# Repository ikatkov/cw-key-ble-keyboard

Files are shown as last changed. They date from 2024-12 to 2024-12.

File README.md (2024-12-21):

# Morse Code Keyer BLE

## Overview
This project is a Bluetooth keyboard for a Morse Code keyer. 

Main purpose is to practice morse code in the Morse Mania iOS app with a real morse code key.

Data flow looks like this

a CW Keyer -over audio-wire-> this BT Keyboard box --over BT-> iPhone

The Morse Mania app expect "[" and "]" buttons, so this Bluetooth keyboard sends key_down and key_up events.

### Battery level
On iOS battery level is visible in Battery widget - Swipe right on the Home Screen to access the Today View.
### Multiple languages
If you have more than one language installed, you must switch to "English" before this BT keyboard connects. If you don't the Morse Mania app would be gettting whatever your national symbols are mapped to the "[" and "]" buttons on the standard keyboard and the app would looks broken.

### Key repeat
You might want to disable auto-key repeat in iOS Settings > Accessibility > Keyboards

## Features
- BLE keyboard functionality
- Tone generation for startup and shutdown
- Voltage detection to monitor battery status, audio bips when voltage is below ~2.9V
- Inactivity 5min auto turn-off

## Usage
- Connect the Arduino to your computer and upload the code.
- Open a BLE-capable device and connect to the "Morse Code Keyer".
- Use the iambic CW paddles to send Morse code.

## Assembly

See schematic and PCB in the  "kicad" folder.
The firmware in the "firmware" folder.

[See interactive PCB 3d view here](https://3dviewer.net/#model=https://github.com/ikatkov/cw-key-ble-keyboard/main/pcb.wrl)

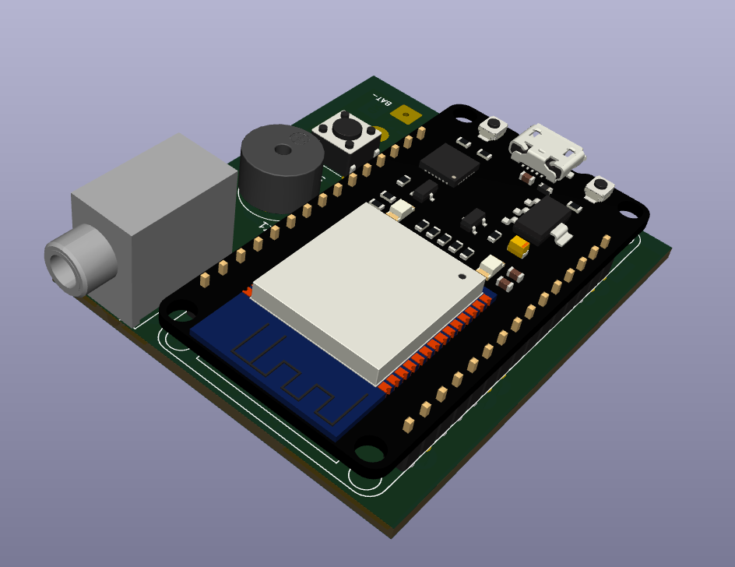
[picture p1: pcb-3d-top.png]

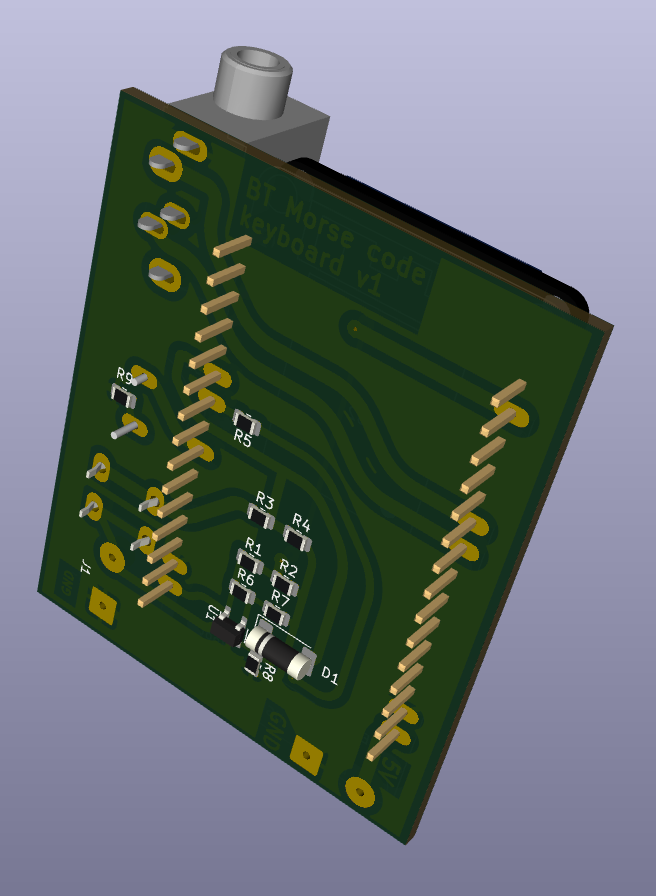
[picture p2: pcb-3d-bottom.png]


## Acknowledgments
- [Arduino](https://www.arduino.cc/)
- [BleKeyboard Library](https://github.com/Teckel12/BLEKeyboard)

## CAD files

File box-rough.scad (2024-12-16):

/* Box design originally by:
////////////////////////////////////////////////////////////////////
              -    FB Aka Heartman/Hearty 2016     -
              -   http://heartygfx.blogspot.com    -
              -       OpenScad Parametric Box      -
              -         CC BY-NC 3.0 License       -
////////////////////////////////////////////////////////////////////

Improved by jbebel:
http://github.com/jbebel/Ultimate-Box-Maker

To create a box, start by modifying the numerical parameters in the sections
below. This can be accomplished using a release of OpenSCAD newer than 2015.03.
As of the time of writing, this means that a development snapshot is required.
The Thingiverse Customizer may also potentially work, but at the time of
writing, it was inoperable.

The simplest choice is to hand-edit the .scad file. Feature toggles are
annotated with a comment. The other numerical parameters are measurements in
mm. Everything is parametrized, so if you double all the non-feature parameters
you will double the box size in every dimension. Certain parameters are derived
from other parameters. If you wish to override them, you may, but sensible
defaults have been chosen. Notably the design in this revision is particularly
PCB-centric, in that you should start with your PCB size and adjust the margins
around it to determine the box size. If you care more about the box size, you
can set the Length, Width, and Height explicitly, but read the comments around
them.

Once your box is sized appropriately, you can use the Panel modules to design
the holes and text for the front and back panels. Helper variables are provided
to assist you in positioning these holes relative to the PCB, if your holes are
for PCB-mounted components.

When you are ready to print, adjust the values in the "STL element to export"
section, and export each part one at a time.

Experimental options are provided for a screwless design, but these are
untested. In particular, the box fixation tabs may need thicknesses adjusted
in order to have the appropriate flexibility.
*/

// preview[view:north east, tilt:top diagonal]
//----------------------- Box parameters ---------------------------

/* [Box options] */
// - Wall thickness
Thick = 2;
// - Panel thickness
PanelThick = 2;
// - Font Thickness
FontThick = 0.5;
// - Filet Radius
Filet = 2;
// - 0 for beveled, 1 for rounded
Round = 1; // [0:No, 1:Yes]
// - Printer margin around interior cutouts
CutoutMargin = 0.3;
// - Margin between mating parts
PartMargin = 0.1;
// - PCB feet? (x4)
PCBFeet = 1; // [0:No, 1:Yes]
// - Decorations?
Decorations = 1; // [0:No, 1:Yes]
// - Decorations to ventilation holes
Vent = 1; // [0:No, 1:Yes]
// - Decoration-Holes width (in mm)
Vent_width = 1.5;
// - Tolerance (Panel/rails gap on one edge)
PanelThickGap = CutoutMargin + PartMargin;
PanelVerticalGap = PartMargin;
PanelHorizontalGap = CutoutMargin + PartMargin;


/* [Box Fixation Tabs] */
// - Side screw hole (or snap) diameter
ScrewHole = 2.2606;
// - Screw thread major diameter for outer shell
BoxHole = 2.8448;
// Thickness of fixation tabs
TabThick = 2;
// Back left tab
BLTab = 1; // [0:Bottom, 1:Top]
// Back right tab
BRTab = 1; // [0:Bottom, 1:Top]
// Front left tab
FLTab = 1; // [0:Bottom, 1:Top]
// Front right tab
FRTab = 1; // [0:Bottom, 1:Top]
// EXPERIMENTAL: Snap tabs
SnapTabs = 0; // [0:Screws, 1:Snaps]


/* [PCB options] */
// - PCB Length
PCBLength = 54;
// - PCB Width
PCBWidth = 68;
// - PCB Thickness
PCBThick = 1.6;
// You likely need to maintain |TabThick| margin on the left and right for tabs
// and whatnot.
// - Margin between front panel and PCB
FrontEdgeMargin = 2;
// - Margin between back panel and PCB
BackEdgeMargin = 2;
// - Margin between left wall and PCB
LeftEdgeMargin = 5;
// - Margin between right wall and PCB
RightEdgeMargin = 5;
// - Margin between top of PCB and box top.
TopMargin = 20;


/* [PCB_Feet] */
// - Foot height above box interior
FootHeight = 3;
// - Foot diameter
FootDia = 8;
// - Hole diameter, or peg for screwless design
FootHole = 0; // tap size for #4 coarse-thread
// - EXPERIMENTAL Screwless design
Screwless = 0; // [0:Screws, 1:Screwless]
FootFilet = FootHeight/4;

// Foot centers are specified as distance from PCB back-left corner.
// X is along the "length" axis, and Y is along the "width" axis.
// - Foot 1 distance from back PCB edge
Foot1X = 5;
// - Foot 1 distance from left PCB edge
Foot1Y = 5;
// - Foot 2 distance from back PCB edge
Foot2X = 5;
// - Foot 2 distance from right PCB edge
Foot2YFromEdge = 5;
Foot2Y = PCBWidth - Foot2YFromEdge;
// - Foot 3 distance from front PCB edge
Foot3XFromEdge = 5;
Foot3X = PCBLength - Foot3XFromEdge;
// - Foot 3 distance from left PCB edge
Foot3Y = 5;
// - Foot 4 distance from front PCB edge
Foot4XFromEdge = 5;
Foot4X = PCBLength - Foot4XFromEdge;
// - Foot 4 distance from right PCB edge
Foot4YFromEdge = 5;
Foot4Y = PCBWidth - Foot4YFromEdge;


/* [STL element to export] */
// - Top shell
TShell = 0; // [0:No, 1:Yes]
// - Bottom shell
BShell = 0; // [0:No, 1:Yes]
// - Front panel
FPanL = 1; // [0:No, 1:Yes]
// - Back panel
BPanL = 0; // [0:No, 1:Yes]
// - Panel holes and text
PanelFeatures = 0; // [0:No, 1:Yes]


/* [Hidden] */
// - Shell color
Couleur1 = "Orange";
// - Panel color
Couleur2 = "OrangeRed";
// - Text color
TextColor = "White";
// - making decorations thicker if it is a vent to make sure they go through
// shell
// Add a small number to Thick in case Filet is 0.
Dec_Thick = Vent ? Thick*1.001 + Filet : Thick/2;
// Separate vents with a square pillar by default.
Dec_Spacing = Thick + Vent_width;
// X offset to center of first vent
Dec_Offset = Thick*2 + PanelThick + PanelThickGap*2 + Dec_Spacing - Vent_width/2;

// Resolution based on Round parameter. Set this first number to something
// smaller to speed up processing. It should always be a multiple of 4.
Resolution = Round ? 100: 4;

/* Calculate box dimensions from PCB. If you want a more box-centric design
   where the outer diameter of the box matters more than the margins around
   the PCB you can set these manually. The PCB will still be placedaccording
   to the left and back margins, and if you want to use the screwless box
   design, you will need to set the TopMargin to
   (Height - Thick*2 - FootHeight - PCBThick)
*/
Length = PCBLength + FrontEdgeMargin + BackEdgeMargin + ((Thick + PanelThick + PanelThickGap*2)*2);
Width = PCBWidth + LeftEdgeMargin + RightEdgeMargin + Thick*2;
Height = FootHeight + PCBThick + TopMargin + Thick*2;
echo("Box: ", Length=Length, Width=Width, Height=Height);
// X position inset of mounting holes and tabs
MountInset = Thick*3 + PanelThick + PanelThickGap*2 + ScrewHole*4;

// Calculate panel dimensions from box dimensions.
PanelWidth = Width - Thick*2 - PanelHorizontalGap*2;
PanelHeight = Height - Thick*2 - PanelVerticalGap*2;


/*  Panel Manager

    Use the below 4 modules to produce holes and text on the front and back
    panels. The holes modules should contain instances of SquareHole or
    CylinderHole defined later in this file. The text modules should contain
    instances of LText or CText defined later in this file. It is
    recommended to use variables that you define for your needs to create
    the size and positions of these objects.
*/

// Calculate board-relative positions with respect to the panel, for
// convenience in placing panel elements.
TopOfBoardWRTPanel = FootHeight + PCBThick - PanelVerticalGap;
LeftEdgeOfBoardWRTFPanel = LeftEdgeMargin - PanelHorizontalGap;
LeftEdgeOfBoardWRTBPanel = RightEdgeMargin - PanelHorizontalGap;
// Visible panel edges
PanelBottomEdge = Thick - PanelVerticalGap;
PanelTopEdge = PanelHeight - Thick + PanelVerticalGap;
PanelLeftEdge = Thick - PanelHorizontalGap;
PanelRightEdge = PanelWidth - Thick + PanelHorizontalGap;


// Holes for front panel
module FPanelHoles() {
    // SquareHole(On/Off, Xpos,Ypos,Length,Width,Filet)
    SquareHole(1, 20, 20, 15, 10, 1);
    SquareHole(1, 40, 20, 15, 10, 1);
    SquareHole(1, 60, 20, 15, 10, 1);
    // CylinderHole(On/Off, Xpos, Ypos, Diameter)
    CylinderHole(1, 27, 40, 8);
    CylinderHole(1, 47, 40, 8);
    CylinderHole(1, 67, 40, 8);
    SquareHole(1, 20, 50, 80, 30, 3);
    CylinderHole(1, 93, 30, 10);
    SquareHole(1, 120, 20, 30, 60, 3);
}


// Text for front panel
module FPanelText() {
    // LText(On/Off, Xpos, Ypos, "Font", Size, "Text", "HAlign", "VAlign")
    LText(1, 20, 83, "Arial Black", 4, "Digital Screen", HAlign="left");
    LText(1, 120, 83, "Arial Black", 4, "Level", HAlign="left");
    LText(1, 20, 11, "Arial Black", 6, "  1     2      3", HAlign="left");
    // CText(On/Off, Xpos, Ypos, "Font", Size, Diameter, Arc(Deg), Starting Angle(Deg),"Text")
    CText(1, 93, 29, "Arial Black", 4, 10, 180, 0,
          ["1", "." , "3", "." , "5", "." , "7", "." , "9", "." , "11"]);
}
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

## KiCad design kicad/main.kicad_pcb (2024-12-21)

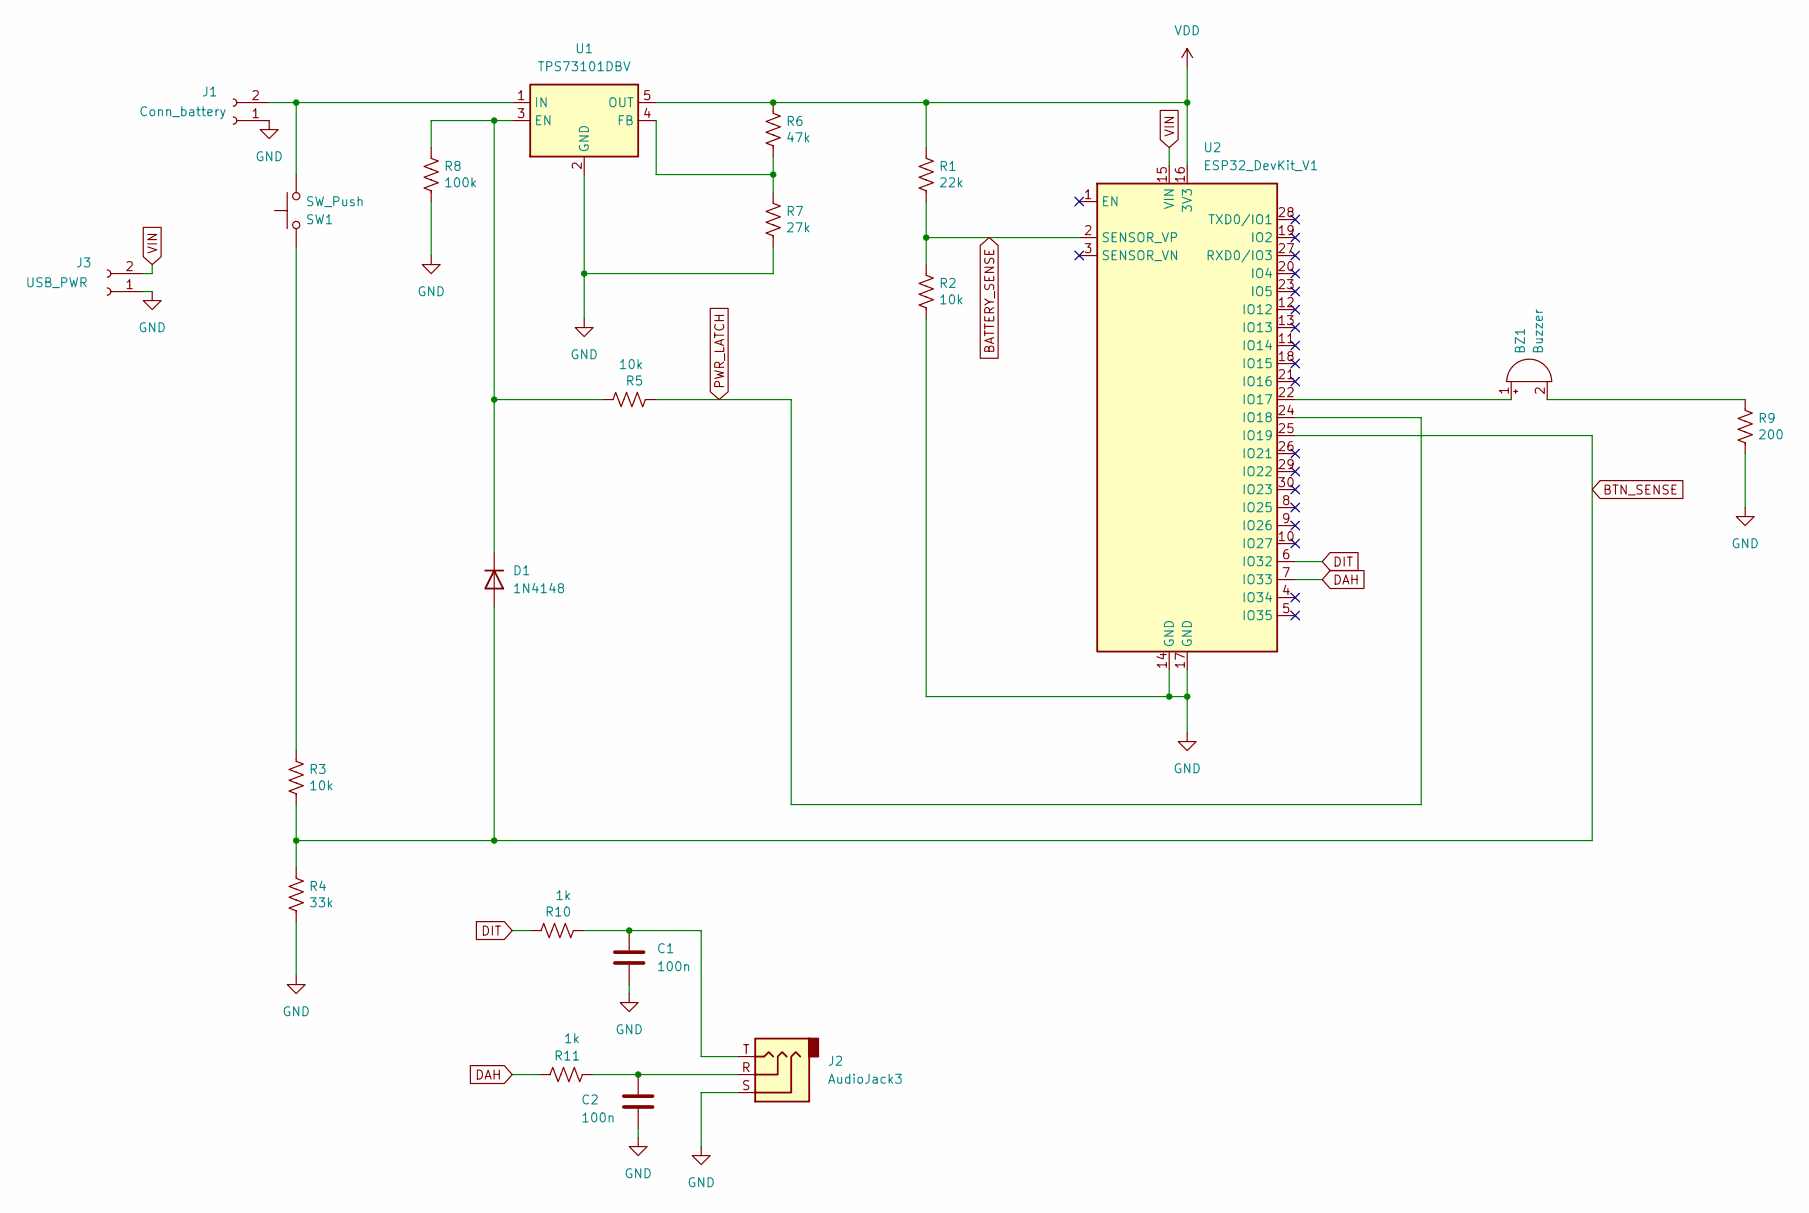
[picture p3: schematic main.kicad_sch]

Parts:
BZ1: Buzzer; Buzzer-GT-0905A
C1, C2: 100n; C_1206_3216Metric
D1: 1N4148; D_MELF
J1: Conn_battery; SolderWire-1.5sqmm_1x02_P6mm_D1.7mm_OD3mm
J2: AudioJack3; Jack_3.5mm_CUI_SJ1-3535NG_Horizontal
J3: USB_PWR; SolderWire-1.5sqmm_1x02_P6mm_D1.7mm_OD3mm
R1: 22k; R_0805_2012Metric
R2, R3, R5: 10k; R_0805_2012Metric
R4: 33k; R_0805_2012Metric
R6: 47k; R_0805_2012Metric
R7: 27k; R_0805_2012Metric
R8: 100k; R_0805_2012Metric
R9: 200; R_0805_2012Metric
R10, R11: 1k; R_0805_2012Metric
SW1: SW_Push; SW_PUSH_6mm
U1: TPS73101DBV; SOT-23-5
U2: ESP32_DevKit_V1; esp32_devkit_v1_doit

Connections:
BATTERY_SENSE: R1.2, R2.1, U2.2 (SENSOR_VP)
BTN_SENSE: D1.2 (A), R3.2, R4.1, U2.25 (IO19)
DAH: R11.1, U2.7 (IO33)
DIT: R10.1, U2.6 (IO32)
GND: C1.2, C2.2, J1.1, J2.S, J3.1, R2.2, R4.2, R7.2, R8.2, R9.2, U1.2 (GND), U2.14 (GND), U2.17 (GND)
unnamed: BZ1.1 (+), U2.22 (IO17)
unnamed: BZ1.2 (-), R9.1
unnamed: C1.1, J2.T, R10.2
unnamed: C2.1, J2.R, R11.2
unnamed: D1.1 (K), R5.1, R8.1, U1.3 (EN)
unnamed: J1.2, SW1.1, U1.1 (IN)
unnamed: R3.1, SW1.2
unnamed: R6.2, R7.1, U1.4 (FB)
PWR_LATCH: R5.2, U2.24 (IO18)
VDD: R1.1, R6.1, U1.5 (OUT), U2.16 (3V3)
VIN: J3.2, U2.15 (VIN)

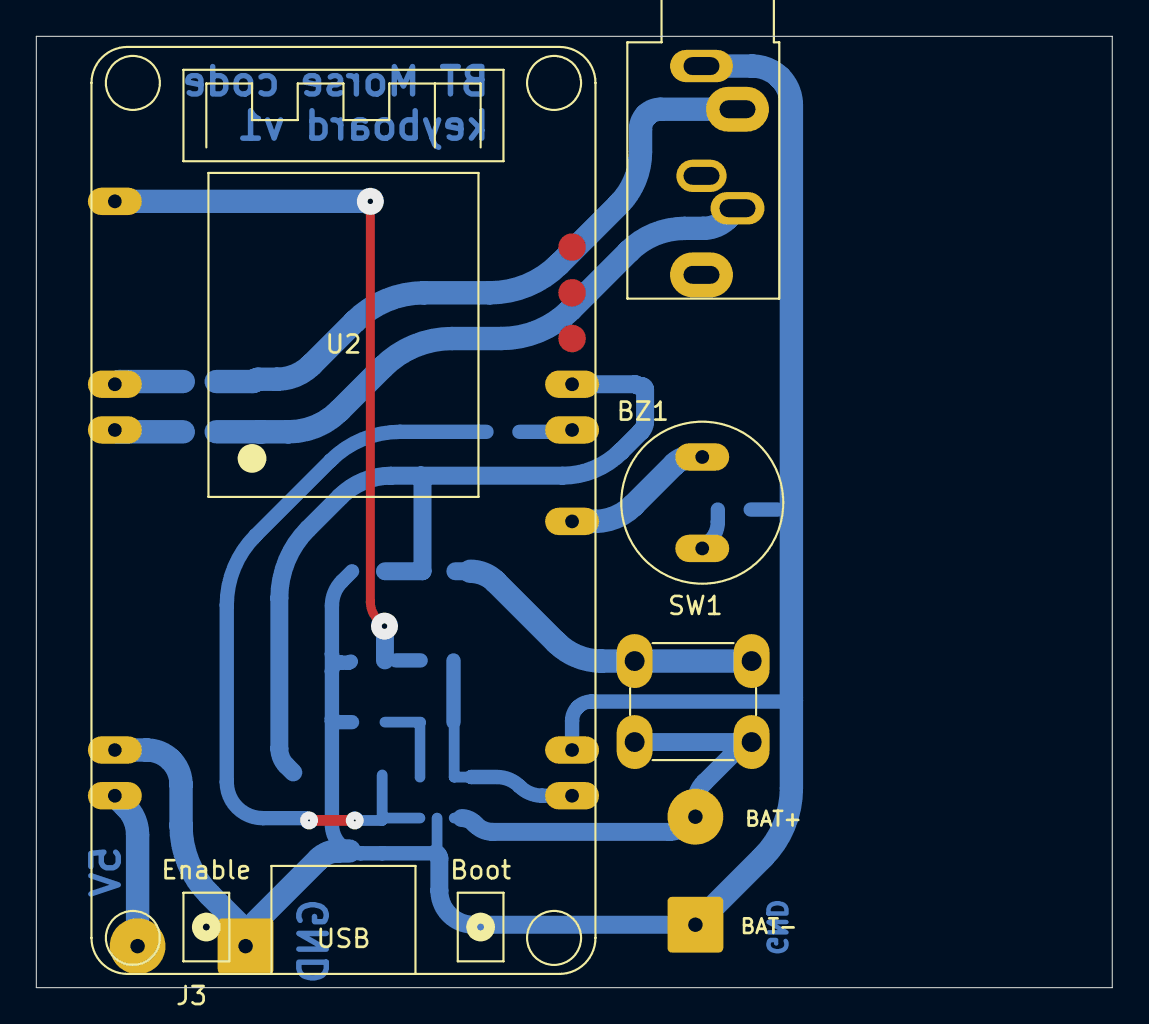
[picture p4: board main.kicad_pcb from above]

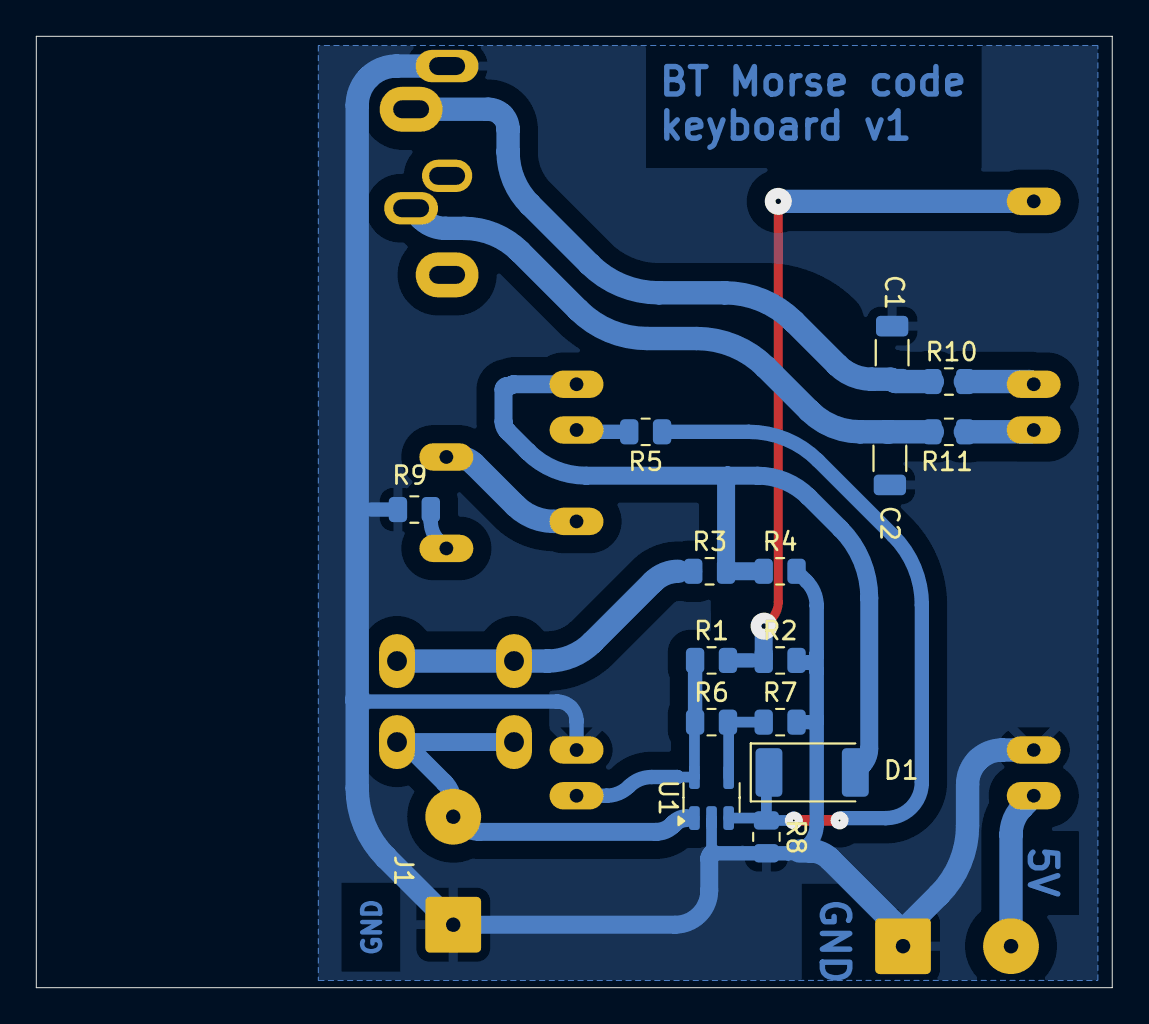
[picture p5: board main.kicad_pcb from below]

Board: 4 copper layers, 59.8 x 52.9 mm, 21 parts (16 on the bottom side), 16 nets.

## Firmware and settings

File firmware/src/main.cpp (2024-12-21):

#include <Arduino.h>
#include <BleKeyboard.h>
#include "soc/soc.h"
#include "soc/rtc_cntl_reg.h"

BleKeyboard bleKeyboard;
// #define PADDLE_DIT_PIN 4
// #define PADDLE_DAH_PIN 5
// #define POWER_LATCH_PIN 18
// #define BUTTON_SENSE_PIN 23
// #define VOLTAGE_DETECTOR_PIN 36
// #define BUZZER_PIN 22
// #define LED_PIN 19

#define PADDLE_DIT_PIN 33
#define PADDLE_DAH_PIN 32

#define VOLTAGE_DETECTOR_PIN 36
#define BUZZER_PIN 17
#define BUTTON_SENSE_PIN 19
#define POWER_LATCH_PIN 18

byte button_dit_oldSwitchState = HIGH;
byte button_dah_oldSwitchState = HIGH;
byte button_pwr_oldSwitchState = HIGH;
const unsigned long debounceTime = 10; // milliseconds
unsigned long button_dit_press_time;
unsigned long button_dah_press_time;
unsigned long button_pwr_press_time;

unsigned long lastLowVoltageCheck;
bool turnoff_countdown;

// Callback function to be called when button1 is pressed
void onDitPressed()
{
  Serial.println("onDitPressed");
  if (bleKeyboard.isConnected())
  {
    bleKeyboard.print("]");
  }
}

// Callback function to be called when button2 is pressed
void onDahPressed()
{
  Serial.println("onDahPressed");
  if (bleKeyboard.isConnected())
  {
    bleKeyboard.print("[");
  }
}

void startup_tone()
{
  tone(BUZZER_PIN, 1000, 200);
  delay(200);
  tone(BUZZER_PIN, 1500, 600);
  delay(600);
}

void shutdown_tone()
{
  tone(BUZZER_PIN, 1500, 200);
  delay(200);
  tone(BUZZER_PIN, 1000, 600);
  delay(600);
}

void setup()
{
  WRITE_PERI_REG(RTC_CNTL_BROWN_OUT_REG, 0);
  pinMode(PADDLE_DIT_PIN, INPUT_PULLUP);
  pinMode(PADDLE_DAH_PIN, INPUT_PULLUP);
  pinMode(VOLTAGE_DETECTOR_PIN, INPUT);
  pinMode(BUTTON_SENSE_PIN, INPUT_PULLDOWN);
  pinMode(POWER_LATCH_PIN, OUTPUT);
  // pinMode(LED_PIN, OUTPUT);
  pinMode(BUZZER_PIN, OUTPUT);
  digitalWrite(POWER_LATCH_PIN, HIGH);

  // digitalWrite(LED_PIN, HIGH);
  // delay(1000);
  // digitalWrite(LED_PIN, LOW);

  analogSetAttenuation(ADC_2_5db);
  analogSetWidth(12);

  Serial.begin(115200);
  while (!Serial)
  {
    ;
  }
  Serial.println("Starting Morse Code Keyer BLE");
  bleKeyboard.setName("Morse Code Keyer");
  bleKeyboard.begin();

  // digitalWrite(LED_PIN, HIGH);
  startup_tone();
  // digitalWrite(LED_PIN, LOW);
  WRITE_PERI_REG(RTC_CNTL_BROWN_OUT_REG, 1);
}

uint8_t mapBatteryValue(uint16_t input) {
    // Ensure the input value is clamped within the source range
    if (input < 800) {
        input = 800;
    } else if (input > 1100) {
        input = 1100;
    }

    // Perform the mapping using linear interpolation
    return (uint8_t)((input - 800) * (100 - 10) / (1100 - 800) + 10);
}
void loop()
{
  if (millis() - 5000 > lastLowVoltageCheck)
  {
    // check VOLTAGE_DETECTOR_PIN
    u_int16_t voltage = analogReadMilliVolts(VOLTAGE_DETECTOR_PIN);    
    lastLowVoltageCheck = millis();
    bleKeyboard.setBatteryLevel(mapBatteryValue(voltage));
    if (voltage < 800)
    {
      Serial.print("Low voltage detected");
      Serial.println(voltage);
      tone(BUZZER_PIN, 1000, 100);
      delay(100);
      tone(BUZZER_PIN, 1000, 100);
      delay(100);
    }
  }

  byte button_dit_switchState = digitalRead(PADDLE_DIT_PIN);
  // has it changed since last time?
  if (button_dit_switchState != button_dit_oldSwitchState)
  {
    // debounce
    if (millis() - button_dit_press_time >= debounceTime)
    {
      turnoff_countdown = false;
      button_dit_press_time = millis();                   // when we closed the switch
      button_dit_oldSwitchState = button_dit_switchState; // remember for next time
      if (button_dit_switchState == LOW)
      {
        Serial.println("DIT down");
        if (bleKeyboard.isConnected())
        {
          bleKeyboard.press(0x5D); //]
        }
      }
      else
      {
        Serial.println("DIT up");
        bleKeyboard.release(0x5D);
      }
    }
  }

  byte button_dah_switchState = digitalRead(PADDLE_DAH_PIN);
  // has it changed since last time?
  if (button_dah_switchState != button_dah_oldSwitchState)
  {
    // debounce
    if (millis() - button_dah_press_time >= debounceTime)
    {
      turnoff_countdown = false;
      button_dah_press_time = millis();                   // when we closed the switch
      button_dah_oldSwitchState = button_dah_switchState; // remember for next time
      if (button_dah_switchState == LOW)
      {
        Serial.println("DAH down");
        if (bleKeyboard.isConnected())
        {
          bleKeyboard.press(0x5B); //[
        }
      }
      else
      {
        Serial.println("DAH up");
        bleKeyboard.release(0x5B);
      }
    }
  }

  if (digitalRead(BUTTON_SENSE_PIN) == HIGH)
  {
    Serial.println("BUTTON_SENSE_PIN HIGH");
    delay(3000);                               // 3 second delay after button pressed
    if (digitalRead(BUTTON_SENSE_PIN) == HIGH) // check if button still pressed and wait till the button is released
    {
      Serial.println("Shutdown manual");
      shutdown_tone();
      // shut down
      digitalWrite(POWER_LATCH_PIN, LOW);
      delay(1000);
    }
  }

  if (!turnoff_countdown && (millis() - max(button_dit_press_time, button_dit_press_time)) > 300000)
  {
    Serial.println("Shutdown count down");
    tone(BUZZER_PIN, 2000, 300);
    delay(500);
    tone(BUZZER_PIN, 2000, 300);
    delay(500);
    tone(BUZZER_PIN, 2000, 300);
    delay(500);
    turnoff_countdown = true;
  }

  if (turnoff_countdown && (millis() - max(button_dit_press_time, button_dit_press_time)) > 320000)
  {
    Serial.println("Shutting down after inactivity");
    shutdown_tone();
    // shut down
    digitalWrite(POWER_LATCH_PIN, LOW);
    delay(1000);
  }
  delay(10);
}

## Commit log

2024-12-11 feat: add buttons support
2024-12-15 moved files and update firmware
    [main.kicad_pcb, main.kicad_sch, main.sch]
2024-12-16 feat: schematic, pcb layout, code, enclosure
    [box-rough.scad, main.kicad_pcb, main.kicad_sch]
2024-12-16 docs: add 3d images and 3d models
    [main.kicad_pcb]
2024-12-21 feat: update schematic with protection RC
    [main.kicad_pcb, main.kicad_sch]
2024-12-21 doc: instructions on how to disable keyboard repeat in iOS, add battery indicator to BLE
